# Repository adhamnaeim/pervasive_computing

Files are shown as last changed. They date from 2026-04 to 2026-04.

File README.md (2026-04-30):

# Allergy Exposure Data Portal

A real-time air quality monitoring system built on a LoRaWAN IoT pipeline. An ESP32 sensor node measures environmental data (temperature, humidity, CO₂, and dust) and transmits it over LoRaWAN to The Things Network. Messages are consumed via MQTT, normalized by MQTTSuite, stored in MariaDB on a Raspberry Pi, and streamed live to a browser dashboard via Server-Sent Events.

```
ESP32 → LoRa → TTN Gateway → TTN → MQTT → MQTTSuite → MariaDB → FastAPI → SSE → Dashboard
```

---

## Hardware

| Component | Model | Quantity |
|---|---|---|
| Microcontroller | AZDelivery ESP32 NodeMCU | 1 |
| Backend server | Raspberry Pi 4 Model B | 1 |
| Router | GL-MT3000 Beryl AX (OpenWRT) | 1 |
| Temperature + Humidity sensor | SHT31 | 1 |
| Dust sensor | PPD42NS | 1 |
| CO₂ sensor | MQ-135 | 1 |
| LoRa module | SX1262 | 1 |

---

## Software Versions

| Software | Version |
|---|---|
| Arduino IDE | 2.3.8 |
| OpenWRT | 25.12.0 |
| Raspberry Pi OS | 64-bit (Bookworm) |
| Raspberry Pi Imager | 2.0.7 |
| Visual Studio Code + PlatformIO | latest |
| MariaDB | system default |
| SNode.C | compiled from source |
| MQTTSuite (mqttcli) | 1.0-rc1 |
| FastAPI | 0.136.1 |
| uvicorn | 0.46.0 |
| mysql-connector-python | 9.7.0 |
| python-dotenv | 1.2.2 |
| sse-starlette | 2.3.6 |
| LoRaWAN Specification | 1.1.0 |
| Regional Parameters | RP001 1.1 revision A |

---

## Repository Structure

```
pervasive_computing/
├── firmware/               # ESP32 PlatformIO firmware
│   └── LoRaWAN-HelloWorld-radiolib/
├── backend/                # FastAPI backend
│   └── main.py
├── frontend/               # Browser dashboard
│   ├── index.html
│   ├── style.css
│   └── dashboard.js
├── mqtt-processing/        # MQTTSuite config and Mqtt.cpp
├── docs/
│   └── 00-setup.md         # IP addresses, credentials, setup notes
├── start.sh                # Launch script
└── README.md
```

---

## Network & Access

| Resource | Value |
|---|---|
| Router IP | `192.168.1.1` |
| Raspberry Pi IP | `192.168.1.188` |
| Raspberry Pi hostname | `admin420` |
| SSH command | `ssh admin420@192.168.1.188` |
| Dashboard URL | http://192.168.1.188:8080 |
| Backend API | http://192.168.1.188:8000 |

---

## Backend API Endpoints

| Endpoint | Description |
|---|---|
| `GET /api/measurements/latest` | Latest 20 events |
| `GET /api/devices` | List of registered devices |
| `GET /events` | SSE route |

---

## TTN Configuration

| Field | Value |
|---|---|
| Console | https://eu1.cloud.thethings.network/console |
| Application ID | `pervasivecomputingcoolrouter` |
| Device ID | `coolrouter-esp32` |
| Frequency Plan | Europe 863–870 MHz (SF9 for RX2) |
| LoRaWAN Version | 1.1.0 |
| Activation | OTAA |
| JoinEUI | `0000000000000000` |
| DevEUI | `70B3D57ED00771C2` |

---

## ESP32 Wiring — SX1262 LoRa Module

| Wire colour | Signal | ESP32 Pin |
|---|---|---|
| Black | Ground | GND |
| Yellow | 3.3V | 3V3 |
| Green | MISO | G19 |
| Orange | MOSI | G23 |
| Blue | CS (NSS) | G5 |
| Brown | CLK (SCK) | G18 |
| White | DIO1 | G26 |

---

## Payload Structure

The ESP32 sends sensor data on separate fPorts:

| fPort | Sensor | Fields |
|---|---|---|
| 1 | Temperature + Humidity | `temperature` (float °C), `humidity` (float %) |
| 2 | CO₂ | `CO2` (float ppm) |
| 4 | Dust | `dust` (int pcs/0.01cf) |

---

## Database Schema

**Database:** `waterq`  
**User:** `snodec`

```sql
CREATE TABLE devices (
  device_id VARCHAR(64) PRIMARY KEY,
  name      VARCHAR(128),
  active    BOOLEAN DEFAULT TRUE
);

CREATE TABLE measurements (
  id         BIGINT AUTO_INCREMENT PRIMARY KEY,
  device_id  VARCHAR(64) NOT NULL,
  ts         TIMESTAMP NOT NULL,
  temp_c     FLOAT NULL,
  humidity   FLOAT NULL,
  co2_ppm    FLOAT NULL,
  dust_pcs   INT NULL,
  raw_json   LONGTEXT NULL,
  FOREIGN KEY (device_id) REFERENCES devices(device_id)
);
```

---

## Running the Project

### Prerequisites

- Raspberry Pi reachable on `192.168.1.188`
- All services installed (MariaDB, SNode.C, MQTTSuite, Python dependencies)

### Start everything

```bash
cd ~/pervasive_computing
./start.sh
```

This launches three processes:
1. **MQTTSuite** (`mqttcli`) — subscribes to TTN MQTT and inserts measurements into MariaDB
2. **FastAPI backend** (`uvicorn`) — REST API on port `8000`
3. **Frontend server** (`python3 -m http.server`) — dashboard on port `8080`

### Access the dashboard

Open in any browser on the local network:
```
http://192.168.1.188:8080
```

---

## MQTT Configuration

The mqttcli config is saved at `~/.config/snode.c/mqttcli.conf`. Simply run:

```bash
mqttcli
```

To reconfigure manually:

```bash
mqttcli in-mqtts --disabled=false \
  session --username pervasivecomputingcoolrouter@ttn \
           --password <IN_THE_REPORT> \
  remote --host eu1.cloud.thethings.network --port 8883 \
  sub --topic "v3/pervasivecomputingcoolrouter@ttn/devices/+/up" \
  db --host localhost --username snodec --password admin420 --database waterq
```

---

## SSH Key Setup (Windows)

IN_THE_REPORT
```

Connect:
```powershell
ssh admin420@192.168.1.188
```

---

## Known Issues & Fixes

| Problem | Fix |
|---|-----|
| Router flashed with wrong firmware | Use sysupgrade image, not factory snapshot |
| SSH key rejected after reflash | Run `ssh-keygen -R 192.168.1.188`, then reconnect |
| Wrong username in SSH (`pi` not found) | Use username set in Raspberry Pi Imager (`admin420`) |
| `mysql-server` not found on Pi | Use `mariadb-server` instead |
| MQTTSuite inserting into wrong table | Edit `Mqtt.cpp` to use correct table name (`measurements`) |
| Backend 500 error on startup | Grant privileges: `GRANT ALL PRIVILEGES ON waterq.* TO 'admin420'@'%'; FLUSH PRIVILEGES;` |
| PlatformIO header files not found | Change relative paths to absolute paths in `platformio.ini` |
| FH network blocking package downloads | Use mobile hotspot for downloads |
| `mqttcli` timing out every 60 seconds | Normal — no uplinks arriving, reconnects automatically |

---

## Group

| Name |
|------|
| Adham Mansour |
| Ahmed Shahien |
| Justus Warm |
| Lukas Mensing |
| Moritz Alker |

**Repository:** https://github.com/adhamnaeim/pervasive_computing  
**Project Board:** https://github.com/users/adhamnaeim/projects/1/

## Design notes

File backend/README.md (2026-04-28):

# Backend – FastAPI

REST API connecting to the MariaDB database on the Raspberry Pi.

## Setup

1. Install dependencies:

   ```bash
   pip install -r requirements.txt
   ```

2. Fill in your credentials in `.env`:

   ```env
   DB_HOST=192.168.1.188
   DB_PORT=3306
   DB_NAME=waterq
   DB_USER=admin420
   DB_PASSWORD=admin420
   ```

3. Run the server:

   ```bash
   uvicorn main:app --reload
   ```

   ```bash
    ~/.local/bin/uvicorn main:app --host 0.0.0.0 --port 8000
   ```

## Endpoints

| Method | URL | Description |
|---|---|---|
| GET | `http://192.168.1.188:8000/api/measurements/latest` | Returns last 20 measurements |
| GET | `http://192.168.1.188:8000/api/devices` | Returns all active devices |

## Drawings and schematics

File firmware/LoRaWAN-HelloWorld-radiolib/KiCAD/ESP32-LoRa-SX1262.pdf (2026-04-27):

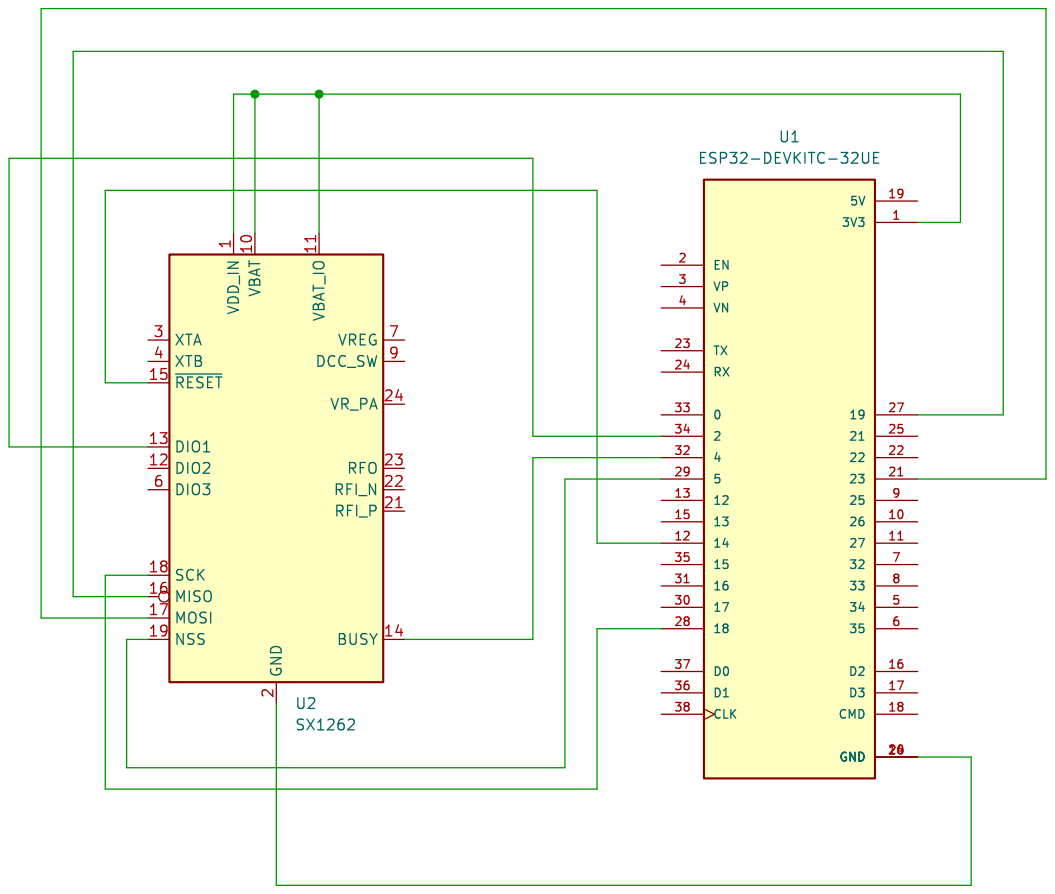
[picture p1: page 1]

29
12 13 13 15 14 12

File: ESP32-LoRa-SX1262.kicad_sch Sheet: / FH-Hagenberg

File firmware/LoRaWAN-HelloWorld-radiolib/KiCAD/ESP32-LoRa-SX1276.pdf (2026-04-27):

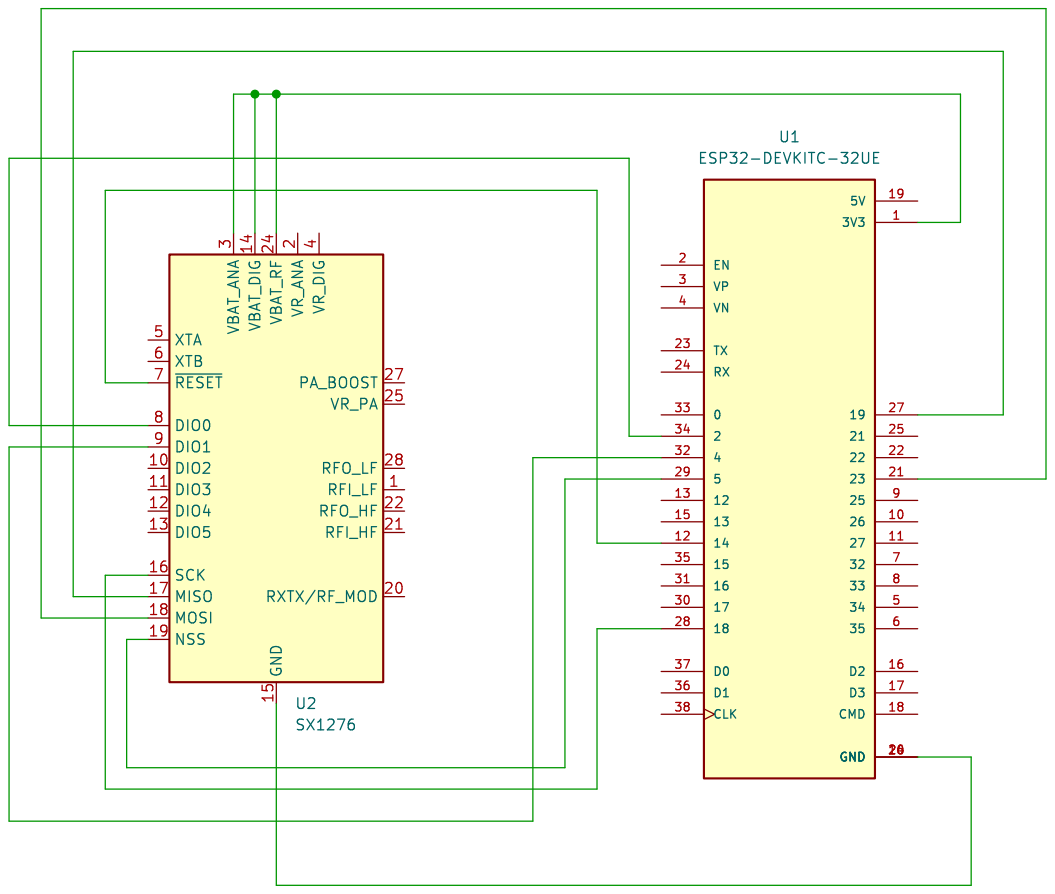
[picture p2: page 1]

29
12 13 13 15 14 12

File: ESP32-LoRa-SX1276.kicad_sch Sheet: / FH-Hagenberg

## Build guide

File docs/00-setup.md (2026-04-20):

Setup for Router:
  - WLAN-Name: CoolRouter

Wifi-Interface:
  - https://192.168.1.1/cgi-bin/luci/
  - Username: root

Raspberry PI:
  - hostname: admin420
  - username: admin420
  - Ipv4 : 192.168.1.188
  - Ipv6 : fd2c:8f35:87f0:0:2ecf:67ff:fe4d:71e0

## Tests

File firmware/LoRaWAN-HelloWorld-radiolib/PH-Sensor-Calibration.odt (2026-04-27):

  Callibration of the PH-Sensor
1. Replace the two files PH4502C.[cpp|h] in your projects with the current ones in my Github repository (https://github.com/PCo-IoT-2024/platform.io/tree/main/LoRaWAN-HelloWorld-radiolib/src).
2. The setup() method of this class no longer requires an argument. Remove the argument in EnvironmentalMonitor.cpp.
  Excerpt from EnvironmentalMonitor.cpp:
  case 2:
    // PH-value
    ph4502c.setup();
    uplinkPayload = std::to_string(ph4502c.getPHLevel());
    fPort = currentSensor + 1;
    break;
3. Determine the raw analog-digital converter (ADC) values of the sensor for the PH values 4, 7 and 10. You can use a very simple Arduino sketch (https://app.arduino.cc/sketches/ce000b8b-fece-46ed-b5cc-3231c651e4ed?view-mode=preview) for this. Compile this sketch for the board type "ESP32 Dev Module" in the Arduino IDE and upload it to your ESP. You can then read the ADC values using the serial monitor (baud rate 119200).
4. Use the hints at https://cwc.com.au/news-events/which-ph-buffer-solution-should-i-use-first-when-calibrating/. I used the sensor's protective cap as a vessel for the buffer liquids. After cleaning, fill it about halfway with the buffer liquids one after the other and screw it onto the sensor. You can now read the ADC values using the serial monitor. Give the sensor 10 to 15 minutes for each liquid so that the value can stabilize. Nevertheless, the value will still fluctuate slightly. Estimate the average value and note it down for PH4, PH7 and PH10. ATTENTION: Start with the PH7 reference and set the potentiometer that is close to the BNC connector to a value around 2048 (center value). It is not very important to hit this value exactly. But 2200 is too high and 1900 is too small. Then use the other two PH references PH4 and PH10 and determine their values as described before.
5. After you have determined the ADC values for the three references, you have to make them known in the "platformio.ini" file. You can use the file in my repository as a template. Finally, three additional macros PH4_ADC_VALUE, PH7_ADC_VALUE and PH10_ADC_VALUE have to be defined as shown below. Your values will obviously be different.
  Excerpt from platformio.ini:
  ; PH value
  [ph]
  build_flags =
    -D PH4502C_PH_PIN=34
    -D PH4502C_TEMPERATURE_PIN=35
    -D PH4_ADC_VALUE=2503
    -D PH7_ADC_VALUE=2080
    -D PH10_ADC_VALUE=1615
6. After you have added these macros, you can translate the code and upload it to the ESP.
7. Now the PH values should arrive correctly in The Things Network. You can check this again with the buffer liquids, vinegar, soapy water, shower gel, etc. Look on google for the approximate PH value of these different liquids.

Let me know if you have any problems.

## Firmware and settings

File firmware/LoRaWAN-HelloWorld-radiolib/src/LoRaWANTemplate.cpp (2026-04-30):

/*

This demonstrates how to save the join information in to permanent memory
so that if the power fails, batteries run out or are changed, the rejoin
is more efficient & happens sooner due to the way that LoRaWAN secures
the join process - see the wiki for more details.

This is typically useful for devices that need more power than a battery
driven sensor - something like a air quality monitor or GPS based device that
is likely to use up it's power source resulting in loss of the session.

The relevant code is flagged with a ##### comment

Saving the entire session is possible but not demonstrated here - it has
implications for flash wearing and complications with which parts of the
session may have changed after an uplink. So it is assumed that the device
is going in to deep-sleep, as below, between normal uplinks.

Once you understand what happens, feel free to delete the comments and
Serial.prints - we promise the final result isn't that many lines.

*/

#if !defined(ESP32)
#pragma error("This is not the example your device is looking for - ESP32 only")
#endif

#include <Preferences.h>

RTC_DATA_ATTR uint16_t bootCount = 0;

#include "GPS.h"
#include "LoRaWAN.hpp"
#include <DHT.h>

#define DHTPIN 15       // Data pin
#define DHTTYPE DHT11   // Sensor type
#define DUSTPIN 16      // Dust sensor data pin

// CO2 defines
#define MQ135PIN 34     // MQ135 CO2 sensor data pin
#define ADC_MAX 4095.0
#define V_ADC 3.3
#define VCC 5.0 
#define RL 10000.0      // Sensor resistor
#define R1 10000.0      // Voltage divider resistor 1
#define R2 20000.0      // Voltage divider resistor 2
#define R0 81626.35     // sensor baseline calibration
#define A 132.32        // curve parameter 1
#define B -2.95         // curve parameter 2

unsigned long duration;
unsigned long starttime;
unsigned long sampletime_ms = 2000;//sampe 30s&nbsp;;
unsigned long lowpulseoccupancy = 0;
float ratio = 0;
float concentration = 0;

static GAIT::LoRaWAN<RADIOLIB_LORA_MODULE> loRaWAN(RADIOLIB_LORA_REGION,
                                                   RADIOLIB_LORAWAN_JOIN_EUI,
                                                   RADIOLIB_LORAWAN_DEV_EUI,
                                                   (uint8_t[16]) {RADIOLIB_LORAWAN_APP_KEY},
#ifdef RADIOLIB_LORAWAN_NWK_KEY
                                                   (uint8_t[16]) {RADIOLIB_LORAWAN_NWK_KEY},
#else
                                                   nullptr,
#endif
                                                   RADIOLIB_LORA_MODULE_BITMAP);

static GAIT::GPS gps(GPS_SERIAL_PORT, GPS_SERIAL_BAUD_RATE, GPS_SERIAL_CONFIG, GPS_SERIAL_RX_PIN, GPS_SERIAL_TX_PIN);
static DHT dht(DHTPIN, DHTTYPE);

// abbreviated version from the Arduino-ESP32 package, see
// https://espressif-docs.readthedocs-hosted.com/projects/arduino-esp32/en/latest/api/deepsleep.html
// for the complete set of options
void print_wakeup_reason() {
    esp_sleep_wakeup_cause_t wakeup_reason = esp_sleep_get_wakeup_cause();
    if (wakeup_reason == ESP_SLEEP_WAKEUP_TIMER) {
        Serial.println(F("Wake from sleep"));
    } else {
        Serial.print(F("Wake not caused by deep sleep: "));
        Serial.println(wakeup_reason);
    }

    Serial.print(F("Boot count: "));
    Serial.println(++bootCount); // increment before printing
}

void goToSleep(uint32_t seconds) {
    loRaWAN.goToSleep();
    gps.goToSleep();

    Serial.println("[APP] Go to sleep");
    Serial.println();

    esp_sleep_enable_timer_wakeup(seconds * 1000UL * 1000UL); // function uses uS
    esp_deep_sleep_start();

    Serial.println(F("\n\n### Sleep failed, delay of 5 minutes & then restart ###\n"));
    delay(5UL * 60UL * 1000UL);
    ESP.restart();
}

void setup() {
    Serial.begin(115200);
    analogSetAttenuation(ADC_11db);

    pinMode(DUSTPIN,INPUT);

    starttime = millis();//get the current time;
    while (!Serial)
        ;        // wait for serial to be initalised
    delay(2000); // give time to switch to the serial monitor

    dht.begin();

    print_wakeup_reason();

    Serial.println(F("Setup"));
    loRaWAN.setup(bootCount);

    loRaWAN.setDownlinkCB([](uint8_t fPort, uint8_t* downlinkPayload, std::size_t downlinkSize) {
        Serial.print(F("[APP] Payload: fPort="));
        Serial.print(fPort);
        Serial.print(", ");
        GAIT::arrayDump(downlinkPayload, downlinkSize);
    });
    Serial.println(F("[APP] Aquire data and construct LoRaWAN uplink"));

    std::string uplinkPayload = RADIOLIB_LORAWAN_PAYLOAD;
    uint8_t fPort = 221;

#define SENSOR_COUNT 3

    uint8_t currentSensor = (bootCount - 1) % SENSOR_COUNT; // Starting at zero (0)

    switch (currentSensor) {
        case 0: {
            // Temperature and Humidity
            float humidity = dht.readHumidity();
            float temperature = dht.readTemperature(); // Celsius
            Serial.println(F("[APP] Read DHT11 sensor:"));
            Serial.print(F("  Humidity: "));
            Serial.print(humidity);
            Serial.print(F("%, Temperature: "));
            Serial.print(temperature);
            Serial.println(F("°C"));

            if (!(isnan(humidity) || isnan(temperature))) {
                fPort = currentSensor + 1; // 1 is humidity and temperature
                uplinkPayload = std::to_string(humidity) + "," + std::to_string(temperature);
            }
            break;
        }
            
        case 1: {
            // CO2
            int adc = analogRead(MQ135PIN);
            float Vmeas = (adc / ADC_MAX) * V_ADC;
            float Vout = Vmeas * ((R1 + R2) / R2);
            if (Vout < 0.01) Vout = 0.01;
            float Rs = RL * ((VCC / Vout) - 1.0);
            float ratio = Rs / R0;
            float co2 = A * pow(ratio, B);
            Serial.println(F("[APP] Read CO2 sensor:"));
            Serial.print(F("  CO2: "));
            Serial.print(co2);
            Serial.println(F(" ppm"));

            if (!isnan(co2)) {
                fPort = currentSensor + 1; // 2 is CO2
                uplinkPayload = std::to_string(co2);
            }
            break;
        }
            
        case 2: {
            // Dust Sensor
            lowpulseoccupancy = 0;
            starttime = millis();
            
            Serial.println(F("[APP] Reading Dust sensor for 30 seconds..."));

            while ((millis() - starttime) < 30000) {
                duration = pulseIn(DUSTPIN, LOW);
                lowpulseoccupancy += duration;
            }

            ratio = lowpulseoccupancy / (30000.0 * 10.0);
            concentration = 1.1*pow(ratio,3) - 3.8*pow(ratio,2) + 520*ratio + 0.62;

            Serial.println(F("[APP] Read Dust sensor:"));
            Serial.print(F("  Dust: "));
            Serial.print(concentration);
            Serial.println(F(" pcs/0.01cf"));

            if (!isnan(concentration)) {
                fPort = currentSensor + 1; // 3 is Dust
                uplinkPayload = std::to_string((uint16_t)(concentration + 0.5)); // Round to nearest integer
            }
            break;
        }
    }

    loRaWAN.setUplinkPayload(fPort, uplinkPayload);
}

void loop() {
    loRaWAN.loop();
}

// Does it respond to a UBX-MON-VER request?
// uint8_t ubx_mon_ver[] = { 0xB5,0x62,0x0A,0x04,0x00,0x00,0x0E,0x34 };

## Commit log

2026-04-20 added code for temperature and humidity measurement
2026-04-27 fixed LoRaWan and set up code for sensors
    [ESP32-LoRa-SX1262.kicad_sch, ESP32-LoRa-SX1276.kicad_sch]
2026-04-28 removed co sensor from html as well
2026-04-28 removed CO Sensor from esp-code
2026-04-30 added real Dust-Sensor code and replaced dummy code
    [LoRaWANTemplate.cpp]
2026-04-30 CO2 sensor integration
2026-04-30 fixed datatype for dust sensor
    [LoRaWANTemplate.cpp]
2026-04-30 switched view
2026-05-04 add grid sensor mapping and click event for sensor selection
